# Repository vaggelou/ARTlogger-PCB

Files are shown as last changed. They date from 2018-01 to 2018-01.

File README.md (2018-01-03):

# ARTlogger-PCB
This is the PCB design of the ARTlogger, a data logging device for the ART16 racecar.

This is the PCB design for the ARTlogger project, a project that was developed in order to produce a data-logger for racing purpose, during my time in Aristotle Racing Team (ART), the Formula Student team of Aristotle University of Thessaloniki, Greece.

This datalogger was used in the ART16, the 5th race car produced by the team.

The PCB was designed using KiCAD, an open source PCB design tool.

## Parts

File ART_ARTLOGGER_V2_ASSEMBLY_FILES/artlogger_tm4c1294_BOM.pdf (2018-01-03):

Id | Designator | Package | Quantity | Designation
1 | C1,C2,C4,C5,C6,C7,C8,C9,C20,C25,C26,C29,C30,C31,C34,C36 | C_0603 | 16 | 100p
2 | C3 | C_0603 | 1 | 3.3n
3 | C10,C12,C14,C15,C18,C21,C24,C27,C28,C33,C37,C40 | C_0603 | 12 | 0.1u
4 | C11,C13,C17,C23 | C_0603 | 4 | 12p
5 | C16 | C_1206 | 1 | 10u
6 | C19 | C_0805 | 1 | 1u
7 | C22 | C_0805 | 1 | 2.2u
8 | C32,C35 | C_0603 | 2 | 560p
9 | C38,C39 | C_0805 | 2 | 4.7u
10 | D1,D2,D3,D4,D5,D6,D8,D9,D11,D12,D13,D14,D15,D16,D17,D18,D22,D23,D24,D25,D26,D27,D28 | SOD-523 | 23 | TVS
11 | D7,D10,D19,D20,D21,D29 | LED-3MM | 6 | Led_Small
12 | P1 | USB_Micro-B | 1 | USB_OTG
13 | R1,R2,R6,R7,R10,R11,R14,R17,R22,R26,R28,R30,R34,R36,R40,R43 | R_0603 | 16 | 150
14 | R3,R4,R8,R9,R12,R13,R16,R18,R24,R27,R29,R31,R35,R37,R41,R44,R50 | R_0603 | 17 | 100
15 | R5,R19 | R_0603 | 2 | 1M
16 | R15,R21,R32,R45,R47,R55,R52 | R_0603 | 7 | 1k
17 | R20 | R_0603 | 1 | 51
18 | R23 | R_0603 | 1 | 2k
19 | R25,R42,R46,R48,R49,R51 | R_0603 | 6 | 10k
20 | R33 | R_0603 | 1 | 510
21 | R38,R39 | R_0603 | 2 | 120
22 | SW1 | SW_PUSH_SMALL | 1 | SW_PUSH
23 | U3 | SOT-223 | 1 | LM2937ET-3.3
24 | U4 | SOT-23-6 | 1 | REF3230
25 | U5 | SO-8 | 1 | MCP2551-I/SN
26 | U6 | Socket_Strip_Straight_1x07 | 1 | microSD
27 | U7 | Socket_Strip_Straight_1x09 | 1 | ULT_GPS
28 | U9 | 5-pin_DBV | 1 | TPS2051B
29 | U11 | Socket_Strip_Straight_1x11 | 1 | MPU9150-Breakout
30 | Y1 | CMR200T | 1 | 32.768kHz
31 | Y2 | NX5032GA | 1 | 25MHz
32 | REF**,REF**,REF**,REF** | 3mm_screw | 4 | 3mm_screw
33 | U8 | IDC_Header_Straight_10pins | 1 | CORTEX_DEBUG
34 | U1 | TQFP-128_14x14mm_Pitch0.4mm | 1 | TM4C1294
35 | U2 | Socket_Strip_Straight_2x13 | 1 | 26POS_CONN

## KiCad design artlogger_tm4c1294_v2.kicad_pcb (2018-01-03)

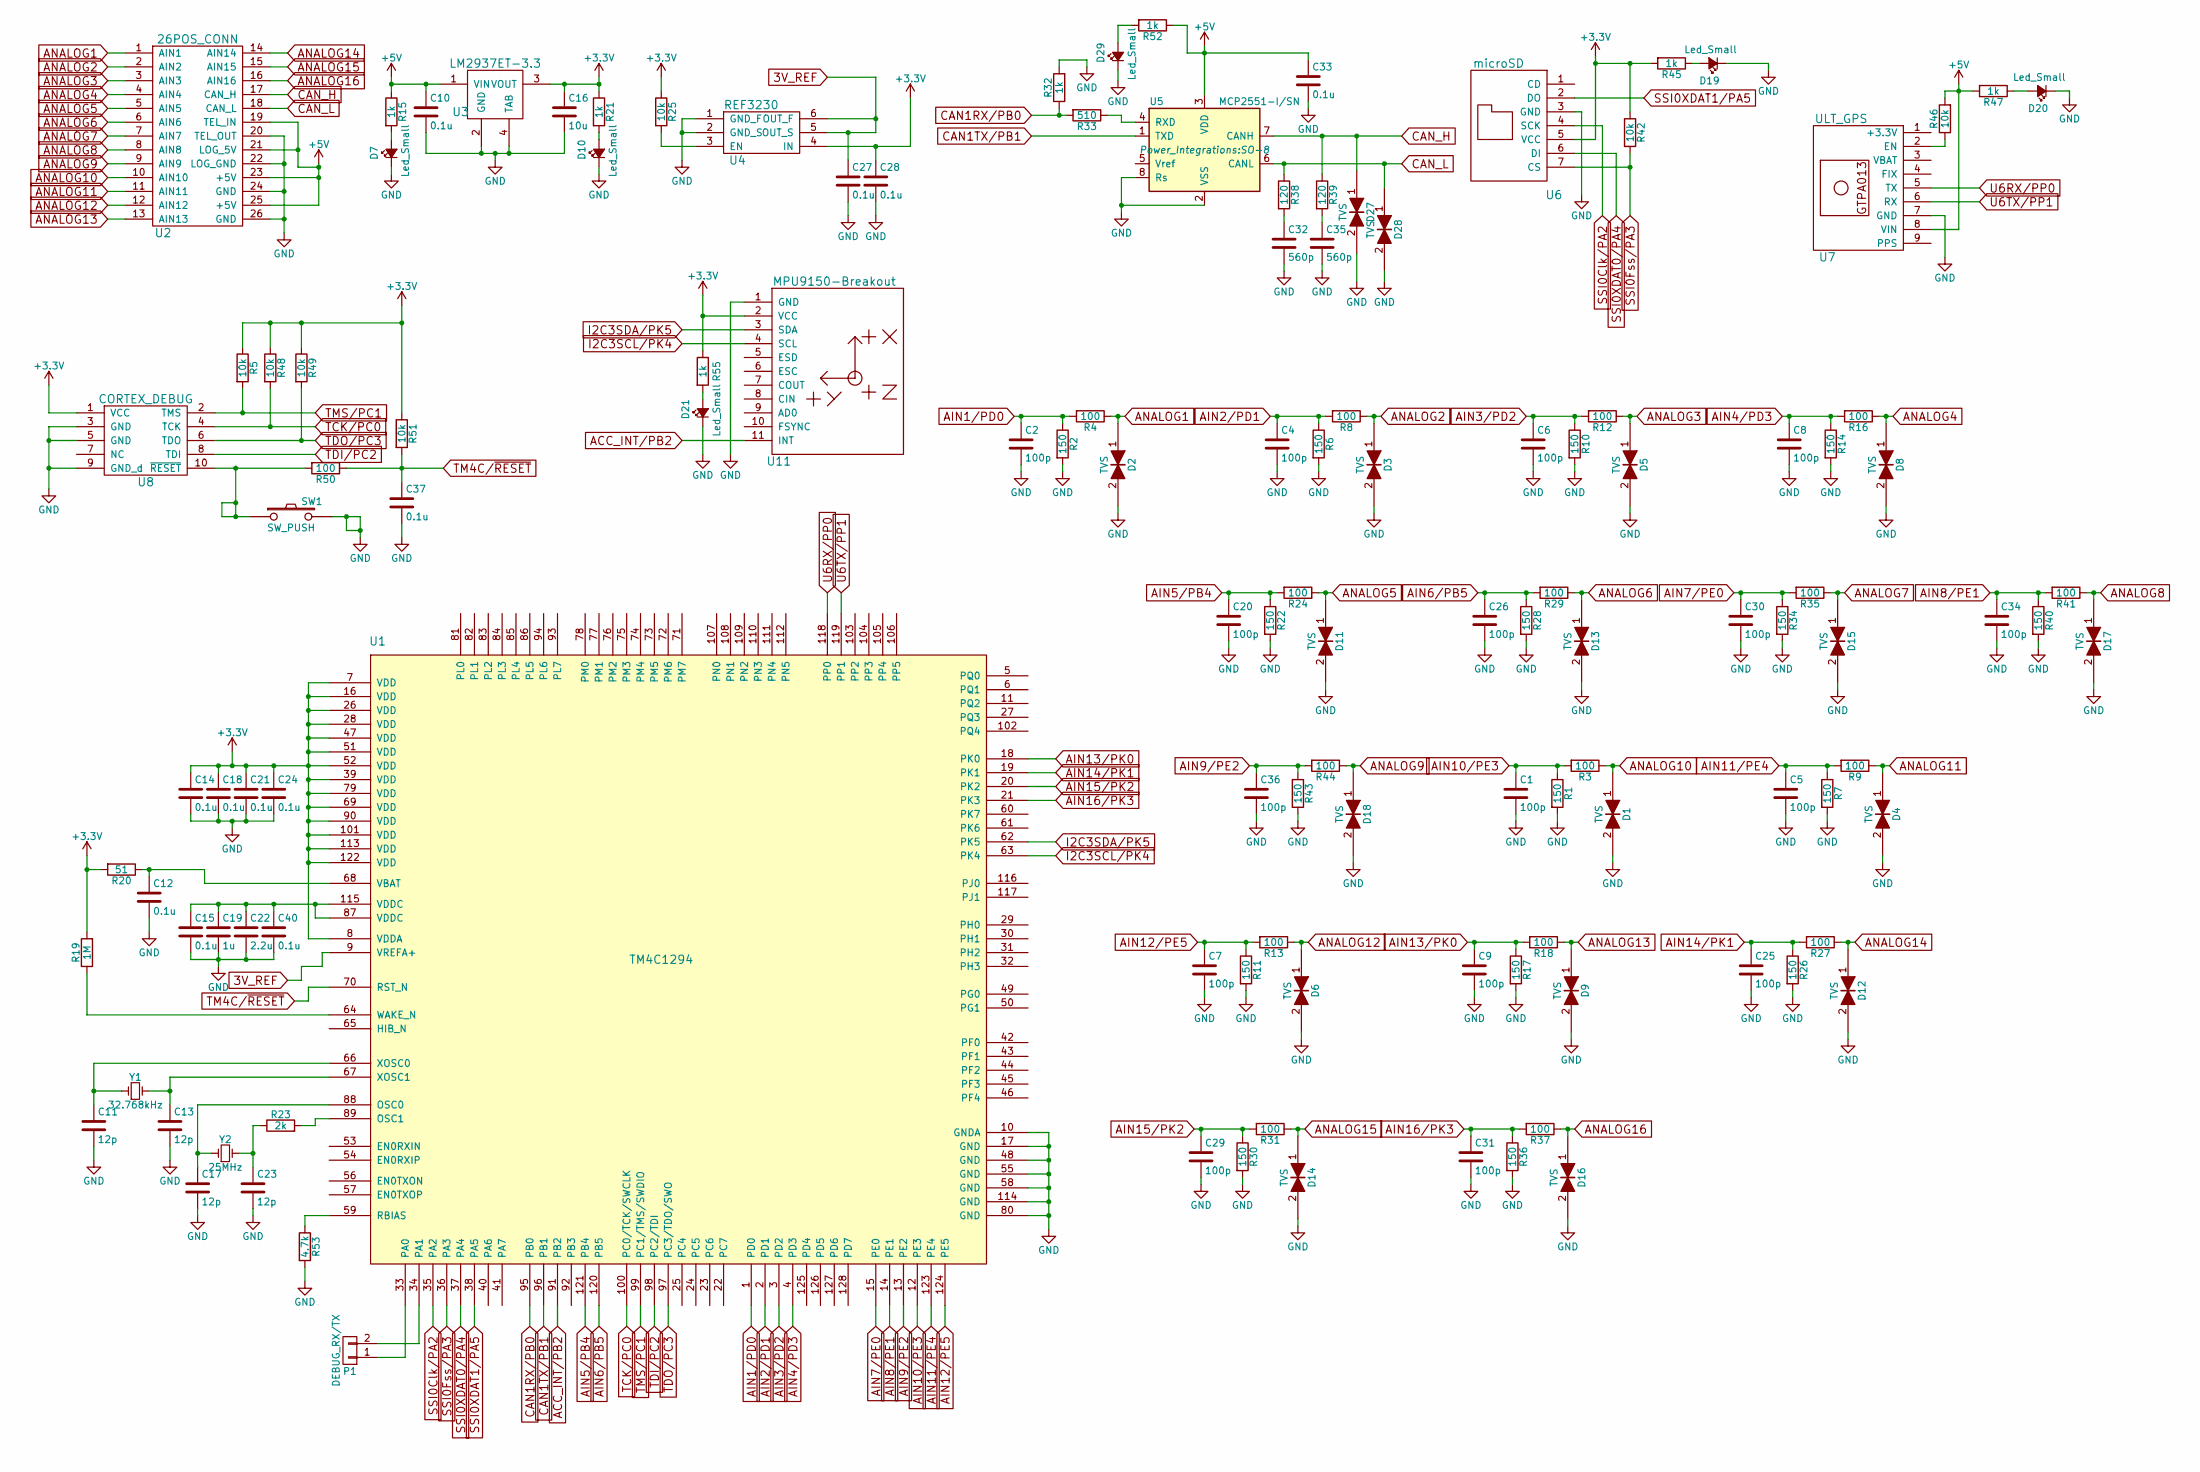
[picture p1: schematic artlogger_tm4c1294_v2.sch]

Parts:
C1, C2, C4, C5, C6, C7, C8, C9, C20, C25, C26, C29, C30, C31, C34, C36: 100p; C_0603
C10, C12, C14, C15, C18, C21, C24, C27, C28, C33, C37, C40: 0.1u; C_0603
C11, C13, C17, C23: 12p; C_0603
C16: 10u; C_1206
C19: 1u; C_0805
C22: 2.2u; C_0805
C32, C35: 560p; C_0603
D1, D2, D3, D4, D5, D6, D8, D9, D11, D12, D13, D14, D15, D16, D17, D18, D27, D28: TVS; SOD-523
D7, D10, D19, D20, D21, D29: Led_Small; LED-3MM
P1: DEBUG_RX/TX; Socket_Strip_Straight_1x02
R1, R2, R6, R7, R10, R11, R14, R17, R22, R26, R28, R30, R34, R36, R40, R43: 150; R_0603
R3, R4, R8, R9, R12, R13, R16, R18, R24, R27, R29, R31, R35, R37, R41, R44, R50: 100; R_0603
R5, R25, R42, R46, R48, R49, R51: 10k; R_0603
R15, R21, R32, R45, R47, R52, R55: 1k; R_0603
R19: 1M; R_0603
R20: 51; R_0603
R23: 2k; R_0603
R33: 510; R_0603
R38, R39: 120; R_0603
R53: 4.7k; R_0603
SW1: SW_PUSH; SW_PUSH_SMALL
U1: TM4C1294; TQFP-128_14x14mm_Pitch0.4mm
U2: 26POS_CONN; Socket_Strip_Straight_2x13
U3: LM2937ET-3.3; SOT-223
U4: REF3230; SOT-23-6
U5: MCP2551-I/SN; SO-8
U6: microSD; Socket_Strip_Straight_1x07
U7: ULT_GPS; Socket_Strip_Straight_1x09
U8: CORTEX_DEBUG; IDC_Header_Straight_10pins
U11: MPU9150-Breakout; Socket_Strip_Straight_1x11
Y1: 32.768kHz; CMR200T
Y2: 25MHz; NX5032GA

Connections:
3V_REF: C27.1, U1.9 (VREFA+), U4.5 (OUT_S), U4.6 (OUT_F)
+3V3: C14.1, C16.1, C18.1, C21.1, C24.1, C28.1, R5.1, R19.2, R20.2, R21.1, R25.1, R42.1, R45.2, R48.1, R49.1, R51.1, R55.1, U1.7 (VDD), U1.8 (VDDA), U1.16 (VDD), U1.26 (VDD), U1.28 (VDD), U1.39 (VDD), U1.47 (VDD), U1.51 (VDD), U1.52 (VDD), U1.69 (VDD), U1.79 (VDD), U1.90 (VDD), U1.101 (VDD), U1.113 (VDD), U1.122 (VDD), U3.3 (VOUT), U4.4 (IN), U6.5 (VCC), U8.1 (VCC), U11.2 (VCC)
+5V: C10.1, C33.1, R15.1, R46.2, R47.2, R52.1, U2.19 (TEL_IN), U2.21 (LOG_5V), U2.23 (+5V), U2.25 (+5V), U3.1 (VIN), U5.3 (VDD), U7.8 (VIN)
ACC_INT/PB2: U1.91 (PB2), U11.11 (INT)
AIN1/PD0: C2.1, R2.1, R4.2, U1.1 (PD0)
AIN2/PD1: C4.1, R6.1, R8.2, U1.2 (PD1)
AIN3/PD2: C6.1, R10.1, R12.2, U1.3 (PD2)
AIN4/PD3: C8.1, R14.1, R16.2, U1.4 (PD3)
AIN5/PB4: C20.1, R22.1, R24.2, U1.121 (PB4)
AIN6/PB5: C26.1, R28.1, R29.2, U1.120 (PB5)
AIN7/PE0: C30.1, R34.1, R35.2, U1.15 (PE0)
AIN8/PE1: C34.1, R40.1, R41.2, U1.14 (PE1)
AIN9/PE2: C36.1, R43.1, R44.2, U1.13 (PE2)
AIN10/PE3: C1.1, R1.1, R3.2, U1.12 (PE3)
AIN11/PE4: C5.1, R7.1, R9.2, U1.123 (PE4)
AIN12/PE5: C7.1, R11.1, R13.2, U1.124 (PE5)
AIN13/PK0: C9.1, R17.1, R18.2, U1.18 (PK0)
AIN14/PK1: C25.1, R26.1, R27.2, U1.19 (PK1)
AIN15/PK2: C29.1, R30.1, R31.2, U1.20 (PK2)
AIN16/PK3: C31.1, R36.1, R37.2, U1.21 (PK3)
ANALOG1: D2.1, R4.1, U2.1 (AIN1)
ANALOG2: D3.1, R8.1, U2.2 (AIN2)
ANALOG3: D5.1, R12.1, U2.3 (AIN3)
ANALOG4: D8.1, R16.1, U2.4 (AIN4)
ANALOG5: D11.1, R24.1, U2.5 (AIN5)
ANALOG6: D13.1, R29.1, U2.6 (AIN6)
ANALOG7: D15.1, R35.1, U2.7 (AIN7)
ANALOG8: D17.1, R41.1, U2.8 (AIN8)
ANALOG9: D18.1, R44.1, U2.9 (AIN9)
ANALOG10: D1.1, R3.1, U2.10 (AIN10)
ANALOG11: D4.1, R9.1, U2.11 (AIN11)
ANALOG12: D6.1, R13.1, U2.12 (AIN12)
ANALOG13: D9.1, R18.1, U2.13 (AIN13)
ANALOG14: D12.1, R27.1, U2.14 (AIN14)
ANALOG15: D14.1, R31.1, U2.15 (AIN15)
ANALOG16: D16.1, R37.1, U2.16 (AIN16)
CAN1RX/PB0: R32.1, R33.2, U1.95 (PB0)
CAN1TX/PB1: U1.96 (PB1), U5.1 (TXD)
CAN_H: D27.1, R39.1, U2.17 (CAN_H), U5.7 (CANH)
CAN_L: D28.1, R38.1, U2.18 (CAN_L), U5.6 (CANL)
GND: C1.2, C2.2, C4.2, C5.2, C6.2, C7.2, C8.2, C9.2, C10.2, C11.2, C12.2, C13.2, C14.2, C15.2, C16.2, C17.2, C18.2, C19.2, C20.2, C21.2, C22.2, C23.2, C24.2, C25.2, C26.2, C27.2, C28.2, C29.2, C30.2, C31.2, C32.2, C33.2, C34.2, C35.2, C36.2, C37.2, C40.2, D1.2, D2.2, D3.2, D4.2, D5.2, D6.2, D7.1 (K), D8.2, D9.2, D10.1 (K), D11.2, D12.2, D13.2, D14.2, D15.2, D16.2, D17.2, D18.2, D19.1 (K), D20.1 (K), D21.1 (K), D27.2, D28.2, D29.1 (K), R1.2, R2.2, R6.2, R7.2, R10.2, R11.2, R14.2, R17.2, R22.2, R26.2, R28.2, R30.2, R32.2, R34.2, R36.2, R40.2, R43.2, R53.2, SW1.2, U1.10 (GNDA), U1.17 (GND), U1.48 (GND), U1.55 (GND), U1.58 (GND), U1.80 (GND), U1.114 (GND), U2.20 (TEL_OUT), U2.22 (LOG_GND), U2.24 (GND), U2.26 (GND), U3.2 (GND), U3.4 (TAB), U4.1 (GND_F), U4.2 (GND_S), U5.2 (VSS), U5.8 (Rs), U6.3 (GND), U7.7 (GND), U8.3 (GND), U8.5 (GND), U8.9 (GND_d), U11.1 (GND)
I2C3SCL/PK4: U1.63 (PK4), U11.4 (SCL)
I2C3SDA/PK5: U1.62 (PK5), U11.3 (SDA)
unnamed: C11.1, U1.66 (XOSC0), Y1.1
unnamed: C12.1, R20.1, U1.68 (VBAT)
unnamed: C13.1, U1.67 (XOSC1), Y1.2
unnamed: C15.1, C19.1, C22.1, C40.1, U1.87 (VDDC), U1.115 (VDDC)
unnamed: C17.1, U1.88 (OSC0), Y2.1
unnamed: C23.1, R23.1, Y2.2
unnamed: C32.1, R38.2
unnamed: C35.1, R39.2
unnamed: D7.2 (A), R15.2
unnamed: D10.2 (A), R21.2
unnamed: D19.2 (A), R45.1
unnamed: D20.2 (A), R47.1
unnamed: D21.2 (A), R55.2
unnamed: D29.2 (A), R52.2
unnamed: R19.1, U1.64 (WAKE_N)
unnamed: R23.2, U1.89 (OSC1)
unnamed: R25.2, U4.3 (EN)
unnamed: R33.1, U5.4 (RXD)
unnamed: R46.1, U7.2 (EN)
unnamed: R50.2, SW1.1, U8.10 (~RESET)
unnamed: R53.1, U1.59 (RBIAS)
SSI0Clk/PA2: U1.35 (PA2), U6.4 (SCK)
SSI0Fss/PA3: R42.2, U1.36 (PA3), U6.7 (CS)
SSI0XDAT0/PA4: U1.37 (PA4), U6.6 (DI)
SSI0XDAT1/PA5: U1.38 (PA5), U6.2 (DO)
TCK/PC0: R48.2, U1.100 (PC0/TCK/SWCLK), U8.4 (TCK)
TDI/PC2: U1.98 (PC2/TDI), U8.8 (TDI)
TDO/PC3: R49.2, U1.97 (PC3/TDO/SWO), U8.6 (TDO)
TM4C/~RESET: C37.1, R50.1, R51.2, U1.70 (RST_N)
TMS/PC1: R5.2, U1.99 (PC1/TMS/SWDIO), U8.2 (TMS)
U0RX/PA0: P1.1, U1.33 (PA0)
U0TX/PA1: P1.2, U1.34 (PA1)
U6RX/PP0: U1.118 (PP0), U7.5 (TX)
U6TX/PP1: U1.119 (PP1), U7.6 (RX)

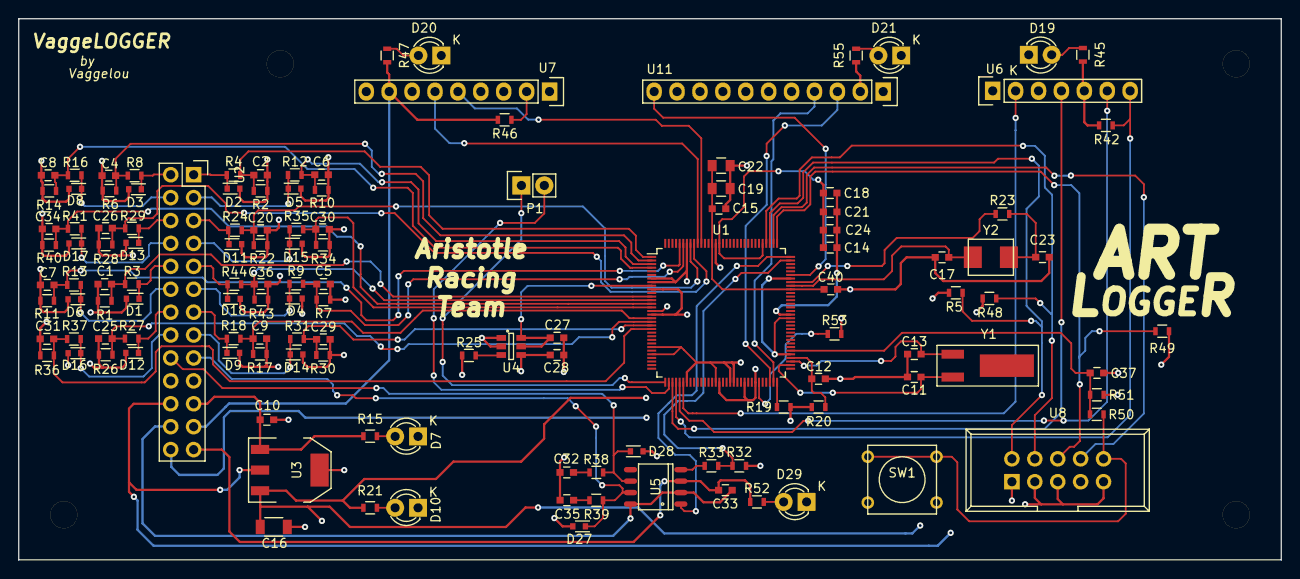
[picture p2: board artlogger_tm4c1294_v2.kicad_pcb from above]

Board: 4 copper layers, 140.0 x 60.0 mm, 128 parts (0 on the bottom side), 77 nets.

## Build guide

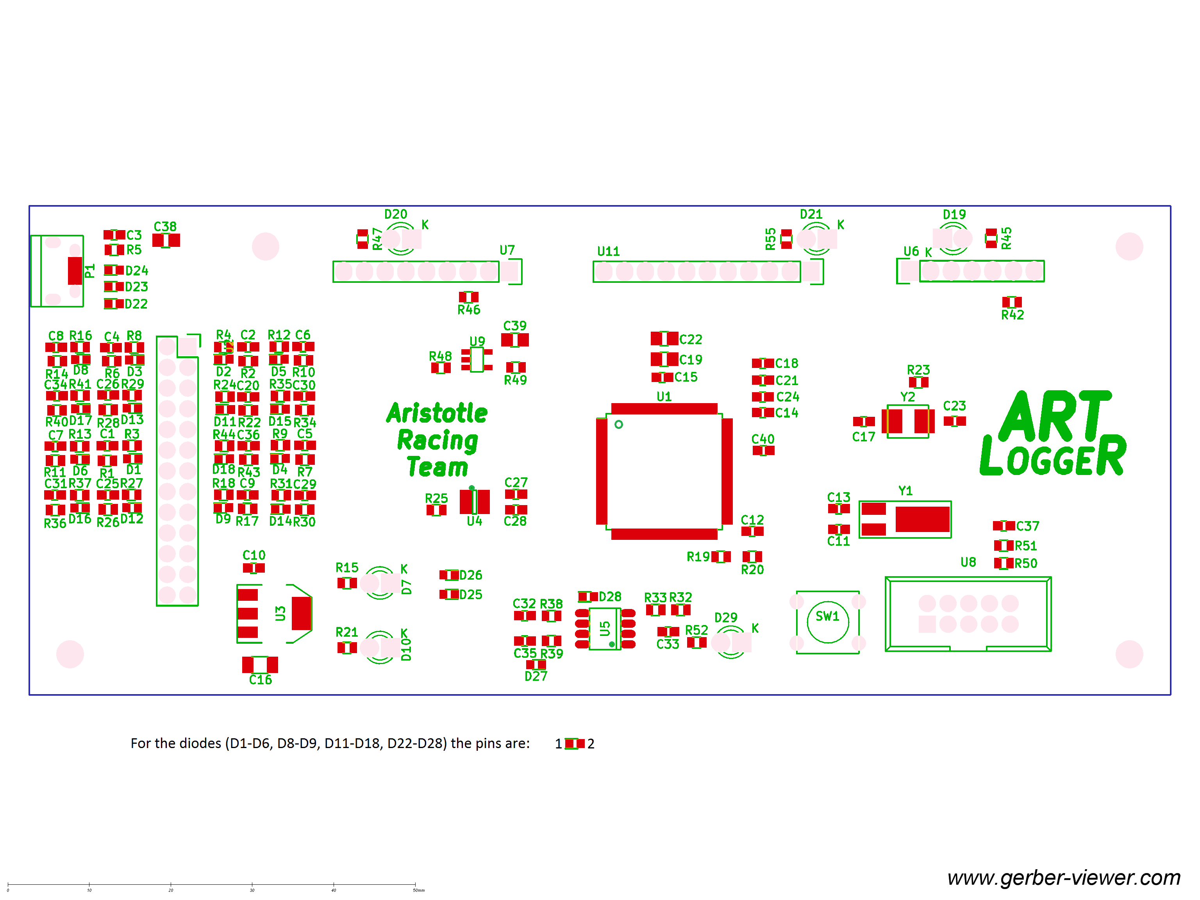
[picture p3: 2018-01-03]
ART_ARTLOGGER_V2_ASSEMBLY_FILES/artlogger_tm4c1294_assembly_drawing.png
